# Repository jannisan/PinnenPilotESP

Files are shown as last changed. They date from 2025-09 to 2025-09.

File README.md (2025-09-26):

# PinnenPilotESP
This project aims to build a simple autopilot, which is able to maintain the magnetic heading. It uses an MPU9250 sensor, a geared DC motor as an actuator and an ESP32 development board as a processor with wifi interface. The motor drives a shaft, which moves the tiller by a cord. The ESP generates a wifi AP with webserver, which enables to control the autopilot with a mobile device. The ESP also calculates a target yaw rate from the difference between actual heading and target heading and gives commands to the motor via a L298 H-bridge module. A small OLED is integrated to show basic information. The code is transferred to the ESP by Arduino IDE via USB.
Most of the mechanical parts are 3d-printed in PETG. The stl-files are included.<br/><br/>
Additional hardware needed:<br/>
DC geared motor 37 mm 12 V, 66 RPM<br/>
L298 H-bridge<br/>
0.91 Inch 128X32 I2C white OLED display<br/>
ESP32 dev board<br/>
2 ball bearings 8 * 22 * 7 mm (from inline skates)<br/>
Wires: 13 * 5cm dupont lines female to female, 2 wires for battery with connector, 2 wires for motor<br/>
3S Lipo battery or similar (6-12V)<br/>
3 screws <br/>
appr. 4 m of cord<br/>



Screenshot_2025-09-26-14-32-38-889_org videolan vlc
Use: When everything is installed and battery is connected the present magnetic heading is stored as target heading and autopilot is active. It starts moving the tiller until the target yaw rate is reached. You can connect to the wifi hotspot "ESP32-Access-Point" with password "123456789" (or change as desired) with your mobile device. Point your webbrowser to 192.178.4.1. Here you can change the target heading, deactivate the autopilot, control the motor manually, go to settings. In settings you could change some parameters and start a magnetic calibration. Settings and calibration values remain stored after poweroff. <br/>
Never forget your lookout, you are responsible for the navigation of your boat at all times!

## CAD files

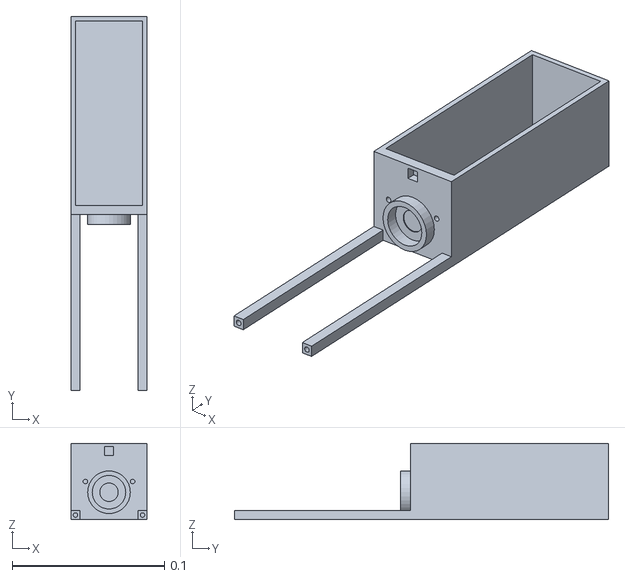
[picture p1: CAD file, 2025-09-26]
PinnenpilotGehäuseBox2.stl
0.05 x 0.245 x 0.05

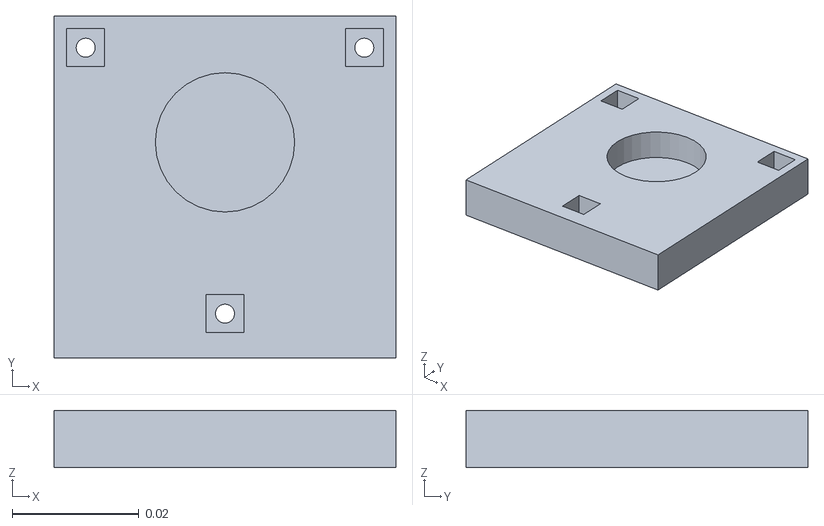
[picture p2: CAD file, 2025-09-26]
PinnenpilotGehäuseBox3.stl
0.054 x 0.054 x 0.009

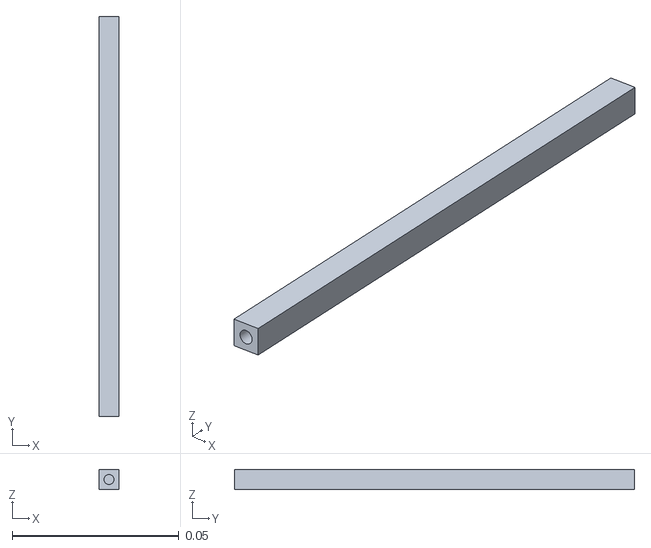
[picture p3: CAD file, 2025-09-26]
PinnenpilotGehäuseBox4.stl
0.006 x 0.12 x 0.006

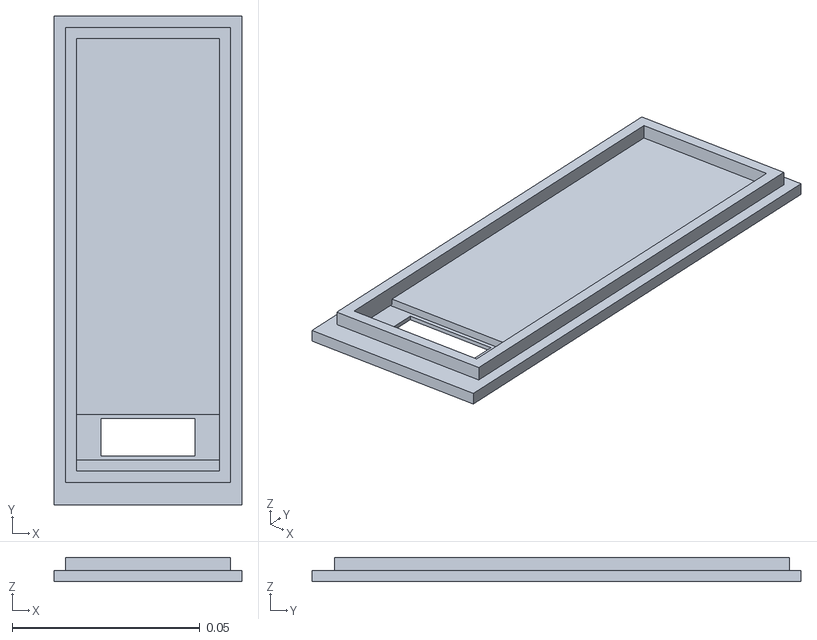
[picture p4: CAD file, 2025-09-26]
PinnenpilotGehäuseBoxDeckel.stl
0.05 x 0.13 x 0.0065

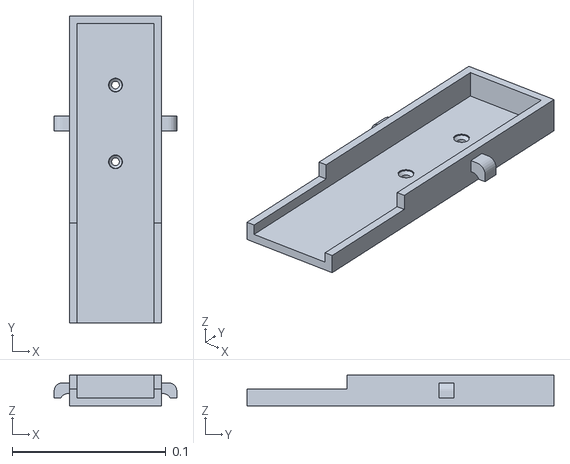
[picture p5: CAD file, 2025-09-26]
PinnenpilotHalterung5.stl
0.08 x 0.2 x 0.02

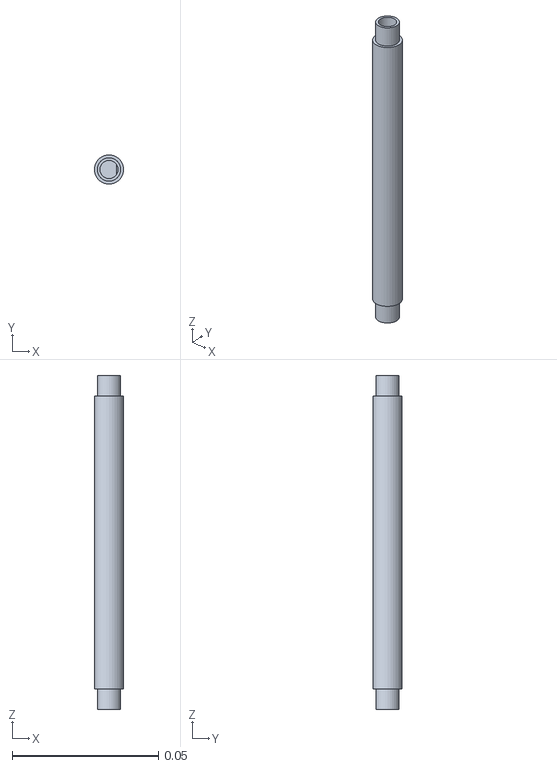
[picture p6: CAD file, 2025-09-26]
PinnenpilotWelle1.stl
0.01 x 0.01 x 0.114

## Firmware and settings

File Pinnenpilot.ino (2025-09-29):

#include <Wire.h>
#include <Adafruit_GFX.h>
#include <Adafruit_SSD1306.h>
#include <Adafruit_Sensor.h>
#include <MPU9250_asukiaaa.h>
#include <WiFi.h>
#include <Preferences.h>

// --- Globale Variablen & Konstanten ---
// SSID und Passwort für den Access Point
const char* ssid = "ESP32-Access-Point";
const char* password = "123456789";

// Setzt den Webserver-Port auf 80
WiFiServer server(80);

// Variable zum Speichern des HTTP-Requests
String header;

// OLED-Display-Einstellungen
#define SCREEN_WIDTH 128
#define SCREEN_HEIGHT 32
#define OLED_RESET -1
#define SCREEN_ADDRESS 0x3C
Adafruit_SSD1306 display(SCREEN_WIDTH, SCREEN_HEIGHT, &Wire, OLED_RESET);

// I2C-Pins für den ESP32-DevKitC
const uint8_t SDA_PIN = 21;
const uint8_t SCL_PIN = 22;

// Instanz der MPU9250-Klasse
MPU9250_asukiaaa mySensor;

// Motor-Pins für den L298N
const int motor1Pin1 = 27;
const int motor1Pin2 = 26;
const int enable1Pin = 14;

// PWM-Einstellungen für den Motor
const int freq = 10000;
const int pwmChannel = 0;
const int resolution = 8;
const int maxMotorSpeed = 255; // Maximaler PWM-Wert für 8-Bit-Auflösung
const int manMotorSpeed = 120; // PWM-Wert im manuellen Modus 
int motorSpeed = 0;
int yrTarget = 0;


// Autopilot-Statusvariablen
float magneticHeading = 0.0;
float targetHeading = 0.0;
float headingError = 0.0;
float gZ = 0.0;
bool autopilotActive = true;

// Komplementär-Filter
float complementaryHeading = 0.0;
const float ALPHA = 0.98;
const float DT = 200.0 / 1000.0;

// Toleranzen
float HEADING_TOLERANCE = 5.0;
float FINE_CONTROL_THRESHOLD = 15.0;
float MAX_GYRO_RATE = 60.0;


// Zeitsteuerung
unsigned long previousMillis = 0;
const long interval = 200;

// Preferences
Preferences preferences;

// --- NEU: Kompass-Kalibrierungswerte ---
float offsetX = 0, offsetY = 0, offsetZ = 0;
float scaleX = 1, scaleY = 1, scaleZ = 1;

// --- Funktionendeklarationen ---
void setupWiFi();
void readSensors();
void controlMotor();
void updateOLED();
void handleWebServer();
void calibrateCompass();
void stopMotor();
void turnLeft();
void turnRight();
void startMotor(int speed);
void saveCalibration();
void loadCalibration();

void setup() {
  Serial.begin(115200);
  while (!Serial);
  Serial.println("Systemstart...");

  // I2C-Bus
  Wire.begin(SDA_PIN, SCL_PIN);
  mySensor.setWire(&Wire);

  // Sensor-Setup
  mySensor.beginAccel();
  mySensor.beginGyro();
  mySensor.beginMag();

  // OLED-Setup
  if (!display.begin(SSD1306_SWITCHCAPVCC, SCREEN_ADDRESS)) {
    Serial.println("SSD1306-Initialisierung fehlgeschlagen");
    for (;;);
  }
  display.setTextSize(2);
  display.setTextColor(SSD1306_WHITE);
  display.clearDisplay();
  display.println("Starting...");
  display.display();

  // Motor-Setup
  pinMode(motor1Pin1, OUTPUT);
  pinMode(motor1Pin2, OUTPUT);
  // Konfiguriert den Pin direkt als PWM-Ausgang
  ledcAttachChannel(enable1Pin, freq, resolution, pwmChannel);

  stopMotor();
  
  // Gespeicherte Kalibrierungswerte laden
  loadCalibration();

  // Initialisiere den stabilisierten Kurs und Sollkurs mit aktuellem Kurs
  readSensors();
  complementaryHeading = magneticHeading;
  targetHeading = complementaryHeading;

  // WiFi-Access-Point starten
  setupWiFi();
}

void loop() {
  unsigned long currentMillis = millis();
  if (currentMillis - previousMillis >= interval) {
    previousMillis = currentMillis;
    readSensors();
    if (autopilotActive) {
      controlMotor();
    }
    updateOLED();
  }
  handleWebServer();
}

// --- WiFi ---
void setupWiFi() {
  Serial.print("Access Point wird gestartet...");
  WiFi.softAP(ssid, password);
  IPAddress IP = WiFi.softAPIP();
  Serial.print("AP IP: ");
  Serial.println(IP);
  server.begin();
}

// --- Preferences ---
void saveCalibration() {
  preferences.begin("compass_cal", false);
  preferences.putFloat("target_h", targetHeading);
  preferences.putFloat("tol", HEADING_TOLERANCE);
  preferences.putFloat("thresh", FINE_CONTROL_THRESHOLD);
  preferences.putFloat("gyro_r", MAX_GYRO_RATE);
  preferences.putFloat("offX", offsetX);
  preferences.putFloat("offY", offsetY);
  preferences.putFloat("offZ", offsetZ);
  preferences.putFloat("sclX", scaleX);
  preferences.putFloat("sclY", scaleY);
  preferences.putFloat("sclZ", scaleZ);
  preferences.end();
  Serial.println("Kalibrierungsdaten gespeichert.");
}

void loadCalibration() {
  preferences.begin("compass_cal", true);
  targetHeading = preferences.getFloat("target_h", targetHeading);
  HEADING_TOLERANCE = preferences.getFloat("tol", HEADING_TOLERANCE);
  FINE_CONTROL_THRESHOLD = preferences.getFloat("thresh", FINE_CONTROL_THRESHOLD);
  MAX_GYRO_RATE = preferences.getFloat("gyro_r", MAX_GYRO_RATE);
  offsetX = preferences.getFloat("offX", 0.0);
  offsetY = preferences.getFloat("offY", 0.0);
  offsetZ = preferences.getFloat("offZ", 0.0);
  scaleX = preferences.getFloat("sclX", 1.0);
  scaleY = preferences.getFloat("sclY", 1.0);
  scaleZ = preferences.getFloat("sclZ", 1.0);
  preferences.end();
  Serial.println("Kalibrierungsdaten geladen.");
}

// Kompass-Kalibrierung ---
void calibrateCompass() {


  float minX = 9999, minY = 9999, minZ = 9999;
  float maxX = -9999, maxY = -9999, maxZ = -9999;

  unsigned long startTime = millis();
  while (millis() - startTime < 20000) { // 20 Sekunden
    mySensor.magUpdate();
    float x = mySensor.magX();
    float y = mySensor.magY();
    float z = mySensor.magZ();

    if (x < minX) minX = x;
    if (y < minY) minY = y;
    if (z < minZ) minZ = z;
    if (x > maxX) maxX = x;
    if (y > maxY) maxY = y;
    if (z > maxZ) maxZ = z;

    delay(100);
    long remaining = (20000 - (millis() - startTime)) / 1000;
    display.clearDisplay();
    display.setCursor(0, 0);
    display.println("Cal...");
    display.setCursor(0, 16);
    display.print("Time: ");
    display.print(remaining);
    display.display();
  }

  // Hard-Iron Offsets
  offsetX = (maxX + minX) / 2.0;
  offsetY = (maxY + minY) / 2.0;
  offsetZ = (maxZ + minZ) / 2.0;

  // Soft-Iron Skalierung
  float avgDelta = ((maxX - minX) + (maxY - minY) + (maxZ - minZ)) / 3.0;
  scaleX = avgDelta / (maxX - minX);
  scaleY = avgDelta / (maxY - minY);
  scaleZ = avgDelta / (maxZ - minZ);

  saveCalibration();

  Serial.println("Kalibrierung abgeschlossen.");
  Serial.printf("Offsets: X=%.2f Y=%.2f Z=%.2f\n", offsetX, offsetY, offsetZ);
  Serial.printf("Scales : X=%.3f Y=%.3f Z=%.3f\n", scaleX, scaleY, scaleZ);

  display.clearDisplay();
  display.setCursor(0, 0);
  display.println("Calibration");
  display.setCursor(0, 16);
  display.println("done!");
  display.display();
  delay(1000);
}

// --- Sensoren ---
void readSensors() {
  mySensor.magUpdate();

  // Rohdaten + Hard/Soft-Iron Korrektur
  float x = (mySensor.magX() - offsetX) * scaleX;
  float y = (mySensor.magY() - offsetY) * scaleY;
  float z = (mySensor.magZ() - offsetZ) * scaleZ;

  magneticHeading = atan2(-x, -y) * 180 / PI;
  if (magneticHeading < 0) {
    magneticHeading += 360;
  }

  // Gyro
  mySensor.gyroUpdate();
  gZ = mySensor.gyroZ();

  // Komplementär-Filter
  float gyroRateTerm = complementaryHeading + gZ * DT;
  float error = magneticHeading - gyroRateTerm;
  if (error > 180) error -= 360;
  if (error < -180) error += 360;

  complementaryHeading = gyroRateTerm + (1.0 - ALPHA) * error;
  if (complementaryHeading >= 360) complementaryHeading -= 360;
  if (complementaryHeading < 0) complementaryHeading += 360;
}

// --- Motorsteuerung ---
void stopMotor() {
  ledcWrite(enable1Pin, 0);
  digitalWrite(motor1Pin1, LOW);
  digitalWrite(motor1Pin2, LOW);
}

void turnLeft() {
  digitalWrite(motor1Pin1, HIGH);
  digitalWrite(motor1Pin2, LOW);
  ledcWrite(enable1Pin, 255 - manMotorSpeed);
}

void turnRight() {
  digitalWrite(motor1Pin1, LOW);
  digitalWrite(motor1Pin2, HIGH);
  ledcWrite(enable1Pin, manMotorSpeed);
}

void startMotor(int speed) {
  if (yrTarget > gZ) {
    digitalWrite(motor1Pin1, LOW);
    digitalWrite(motor1Pin2, HIGH);
    ledcWrite(enable1Pin, speed);
    Serial.print("R");
  } else {
    digitalWrite(motor1Pin1, HIGH);
    digitalWrite(motor1Pin2, LOW);
    ledcWrite(enable1Pin, 255 - speed);
    Serial.print("L");
  }
  Serial.println(speed);
  Serial.println(yrTarget);
}

// --- Autopilot ---
void controlMotor() {
  // P-Regler-Logik für kontinuierliche Korrektur
  headingError = complementaryHeading - targetHeading;
  if (headingError > 180) {
    headingError -= 360;
  }
  if (headingError < -180) {
    headingError += 360;
  }

  if (abs(headingError) > FINE_CONTROL_THRESHOLD) {
    // Aggressive Steuerung (P-Regler) bei großer Abweichung
    motorSpeed = maxMotorSpeed;
    if (headingError > 0) {
      yrTarget = - 5;
      //turnLeft(motorSpeed);
    } else {
      yrTarget = 5;
      //turnRight(motorSpeed);
    }
    startMotor(motorSpeed);
  }
  // Abweichung zwischen 5 und 15 Grad (sanfte Steuerung)
  else if (abs(headingError) > HEADING_TOLERANCE) {
    motorSpeed = int(maxMotorSpeed / 2);
    if (headingError > 0) {
      yrTarget = - 2;
      //turnLeft(motorSpeed);
    } else {
      yrTarget = 2;
      //turnRight(motorSpeed);
    }
    startMotor(motorSpeed);
  }
  // Abweichung weniger als 5 Grad (Dämpfung durch Gyro)
  else {
    // Gyroskop-basierte Dämpfung, um ein Überschwingen zu verhindern
    // Steuerung basierend auf der Drehrate gZ
    yrTarget = 0;
    if (abs(gZ) > 1.5) { // Kleiner Schwellenwert, um Rauschen zu ignorieren
      motorSpeed = int(maxMotorSpeed / 2);
      startMotor(motorSpeed);
    }
    else {
      stopMotor();
    }
  }
}

// --- OLED ---
void updateOLED() {
  char chStr[4];
  char thStr[4];
  char gzStr[4];

  sprintf(chStr, "%03d", (int)complementaryHeading);
  sprintf(thStr, "%03d", (int)targetHeading);
  sprintf(gzStr, "%02d", (int)gZ);

  display.clearDisplay();
  display.setCursor(0, 0);
  display.print("MH");
  display.print(chStr);
  display.println(autopilotActive ? " HDG" : " MAN");
  display.setCursor(0, 16);
  display.print("MC");
  display.print(thStr);
  display.print(" gZ");
  display.println(gzStr);
  display.display();
}

// --- Webserver ---
void handleWebServer() {
  WiFiClient client = server.available();
  if (!client) {
    return;
  }

  String requestLine = "";
  String header = "";
  String postData = "";
  bool isPost = false;
  int contentLength = 0;

  // Lese die erste Zeile der Anfrage
  requestLine = client.readStringUntil('\n');

  // Lese restliche Header und suche nach Content-Length
  while (client.connected() && client.available()) {
    String line = client.readStringUntil('\n');
    header += line;
    if (line.startsWith("Content-Length: ")) {
      contentLength = line.substring(16).toInt();
    }
    if (line.length() == 1 && line.charAt(0) == '\r') {
      // End of headers
      break;
    }
  }

  // Lese den POST-Body, falls es sich um einen POST-Request handelt
  if (requestLine.startsWith("POST") && contentLength > 0) {
    isPost = true;
    char postBuffer[contentLength + 1];
    client.readBytes(postBuffer, contentLength);
    postBuffer[contentLength] = '\0';
    postData = String(postBuffer);

    // Parsen der POST-Daten
    int toleranceIndex = postData.indexOf("tolerance=");
    if (toleranceIndex != -1) {
      String toleranceStr = postData.substring(toleranceIndex + 10);
      int andIndex = toleranceStr.indexOf('&');
      if (andIndex != -1) {
        toleranceStr = toleranceStr.substring(0, andIndex);
      }
      HEADING_TOLERANCE = toleranceStr.toInt();
    }

    int thresholdIndex = postData.indexOf("threshold=");
    if (thresholdIndex != -1) {
      String thresholdStr = postData.substring(thresholdIndex + 10);
      int andIndex = thresholdStr.indexOf('&');
      if (andIndex != -1) {
        thresholdStr = thresholdStr.substring(0, andIndex);
      }
      FINE_CONTROL_THRESHOLD = thresholdStr.toInt();
    }

    int gyroRateIndex = postData.indexOf("gyro_rate=");
    if (gyroRateIndex != -1) {
      String gyroRateStr = postData.substring(gyroRateIndex + 10);
      MAX_GYRO_RATE = gyroRateStr.toInt();
    }

    saveCalibration();
  }

  // --- Verarbeite die Befehle basierend auf der requestLine ---
  bool commandExecuted = false;

  // Manuelle Buttons (nur im AP off-Modus)
  if (!autopilotActive) {
    if (requestLine.indexOf("GET /left") >= 0) {
      turnLeft();
      commandExecuted = true;
    } else if (requestLine.indexOf("GET /stop") >= 0) {
      stopMotor();
      commandExecuted = true;
    } else if (requestLine.indexOf("GET /right") >= 0) {
      turnRight();
      commandExecuted = true;
    }
  }

  // AP-Steuerung
  if (requestLine.indexOf("GET /plus") >= 0) {
    targetHeading = (targetHeading + 10);
    commandExecuted = true;
  } else if (requestLine.indexOf("GET /minus") >= 0) {
    targetHeading = (targetHeading - 10);
    commandExecuted = true;
  } else if (requestLine.indexOf("GET /sync") >= 0) {
    targetHeading = complementaryHeading; // Verwende stabilisierten Kurs zum Synchronisieren
    commandExecuted = true;
  } else if (requestLine.indexOf("GET /toggle") >= 0) {
    autopilotActive = !autopilotActive;
    if (!autopilotActive) {
      stopMotor();
    }
    commandExecuted = true;
  } else if (requestLine.indexOf("GET /calibrate") >= 0) {
    calibrateCompass();
    commandExecuted = true;
  }

  // Wenn ein Befehl ausgeführt wurde oder POST-Daten empfangen wurden, umleiten
  if (commandExecuted || isPost) {
    client.println("HTTP/1.1 302 Found");
    client.println("Location: /");
    client.println("Connection: close");
    client.println();
    client.stop();
    return;
  }

  // Kurs normalisieren
  if (targetHeading >= 360) targetHeading -= 360;
  if (targetHeading < 0) targetHeading += 360;

  // --- Hier wird die Webseite generiert, abhängig von der URL ---

  // Sende HTTP-Header
  client.println("HTTP/1.1 200 OK");
  client.println("Content-type:text/html");
  client.println("Connection: close");
  client.println();

  // HTML für die Settings-Seite
  if (requestLine.indexOf("GET /settings") >= 0) {
    // KEIN REFRESH-TAG
    client.println("<!DOCTYPE html><html><head><meta name='viewport' content='width=device-width, initial-scale=1'><style>html { font-family: Helvetica; display: inline-block; margin: 0px auto; text-align: center;} body { margin: 0; padding: 20px;} .button { border: none; color: white; padding: 16px 40px; text-decoration: none; font-size: 30px; margin: 2px; cursor: pointer; border-radius: 8px;} .button-container { display: flex; justify-content: center; gap: 10px;}.green-button {background-color: #4CAF50;}.red-button {background-color: #f44336;}.blue-button {background-color: #008CBA;}.status-text {font-size: 1.5em;} input[type=number] { width: 80px; padding: 5px; margin: 5px; font-size: 1em;}.form-container {display: flex; flex-direction: column; align-items: center; gap: 10px; border: 2px solid #ccc; padding: 10px; border-radius: 8px;}</style></head><body>");

    client.println("<h2>Settings</h2>");
    client.println("<form action='/' method='POST' class='form-container'>");
    client.println("<label for='tolerance'>MH-tolerance (&deg;):</label>");
    client.println("<input type='number'  name='tolerance' value='" + String(HEADING_TOLERANCE) + "' required>");
    client.println("<label for='threshold'>threshold finecontrol (&deg;):</label>");
    client.println("<input type='number' name='threshold' value='" + String(FINE_CONTROL_THRESHOLD) + "' required>");
    client.println("<label for='gyro_rate'>max. gyrorate (&deg;/s):</label>");
    client.println("<input type='number' name='gyro_rate' value='" + String(MAX_GYRO_RATE) + "' required>");
    client.println("<button type='submit' class='button green-button'>save</button>");
    client.println("</form>");

    client.println("<p class='button-container' style='margin-top: 20px;'>");
    client.println("<a href='/calibrate'><button class='button blue-button'>calibrate compass</button></a>");
    client.println("<a href='/'><button class='button green-button'>back</button></a>");
    client.println("</p>");

    client.println("</body></html>");
    client.println();
    client.stop();
  }

  // HTML für die Hauptseite
  else {
    // Bestimmt die CSS-Klasse für den AP-Button basierend auf dem Status
    String apButtonClass = autopilotActive ? "green-button" : "red-button";

    // Formatiert die Kurswerte als dreistellige Strings mit führenden Nullen
    char chStr[4];
    char thStr[4];
    sprintf(chStr, "%03d", (int)complementaryHeading);
    sprintf(thStr, "%03d", (int)targetHeading);

    // HIER WIRD DER REFRESH-TAG EINGEFÜGT
    client.println("<!DOCTYPE html><html><head><meta name='viewport' content='width=device-width, initial-s cal e=1'><meta http-equiv='refresh' content='5'><style>html { font-family: Helvetica; display: inline-block; margin: 0px auto; text-align: center;} body { margin: 0; padding: 20px;} .button { border: none; color: white; padding: 16px 40px; text-decoration: none; font-size: 30px; margin: 2px; cursor: pointer; border-radius: 8px;} .button-container { display: flex; justify-content: center; gap: 10px;}.green-button {background-color: #4CAF50;}.red-button {background-color: #f44336;}.blue-button {background-color: #008CBA;}.status-text {font-size: 1.5em;} input[type=number] { width: 80px; padding: 5px; margin: 5px; font-size: 1em;}.form-container {display: flex; flex-direction: column; align-items: center; gap: 10px; border: 2px solid #ccc; padding: 10px; border-radius: 8px;}</style></head><body>");

    // Anzeige des Status in fünf separaten Zeilen
    client.println("<p style='font-size: 2em; font-weight: bold;'>MH: " + String(chStr) + "</p>");
    client.println("<p style='font-size: 2em; font-weight: bold;'>target: " + String(thStr) + "</p>");
    client.println("<p style='font-size: 2em; font-weight: bold;'>AP: " + String(autopilotActive ? "ON" : "OFF") + "</p>");
    client.println("<p class='button-container'>");
    client.println("<a href='/minus'><button class='button green-button'>-10&deg;</button></a>");
    client.println("<a href='/plus'><button class='button green-button'>+10&deg;</button></a>");
    client.println("</p>");
    client.println("<p class='button-container'>");
    client.println("<a href='/sync'><button class='button green-button'>sync MH</button></a>");
    client.println("</p>");
    client.println("<p class='button-container'>");
    client.println("<a href='/toggle'><button class='button " + apButtonClass + "'>AP on/off</button></a>");
    client.println("</p>");

    //Buttons, nur im AP off-Modus anzeigen
    if (!autopilotActive) {
      client.println("<p class='button-container'>");
      client.println("<a href='/left'><button class='button green-button'>L</button></a>");
      client.println("<a href='/stop'><button class='button red-button'>Stop</button></a>");
      client.println("<a href='/right'><button class='button green-button'>R</button></a>");
      client.println("</p>");
    }

    //Settings-Button
    client.println("<hr>");
    client.println("<p class='button-container'>");
    client.println("<a href='/settings'><button class='button blue-button'>settings</button></a>");
    client.println("</p>");

    client.println("</body></html>");
    client.println();
    client.stop();
  }
}

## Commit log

2025-09-26 Update Pinnenpilot.ino
    calibration implemented
2025-09-29 Update Pinnenpilot.ino
    Fehler in ledcwrite() korrigiert
    [Pinnenpilot.ino]
